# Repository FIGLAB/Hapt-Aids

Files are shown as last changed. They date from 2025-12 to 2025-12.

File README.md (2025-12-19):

# Hapt-Aids: Self-Powered, On-Body Haptics for Activity Monitoring
This is the repository for Hapt-Aids, presented at UBICOMP 2025. Check out the [full paper here](https://drive.google.com/file/d/1-sPkwGhYdYCn-X2jhVIx13SwtfONY48X/view?usp=sharing)!
Feel free to contact me with any questions!

The JLCPCB folder can be directly uploaded, and should also contain instructions for assembly of the PCB with all components other than the supercapacitor and the vibration motor.

If you want to edit the files, open the project in KICAD.
The full parts list can be found in the Bill of Materials.

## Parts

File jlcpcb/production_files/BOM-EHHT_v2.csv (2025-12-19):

Comment | Designator | Footprint | LCSC
MCR16 | D3 | MCR16
A+ | H4 | PinHeader_1x01_P1.00mm_Vertical
0.01uF | CREF1 | Capacitor_SMD:C_0402_1005Metric
O+ | H13 | PinHeader_1x01_P1.00mm_Vertical
4.42M | RUV2 | Resistor_SMD:R_0402_1005Metric
0.1uF | CBYP1 | Capacitor_SMD:C_0402_1005Metric
4.7uF | CHVR1 | Capacitor_SMD:C_0402_1005Metric
10M | ROC1 | Resistor_SMD:R_0402_1005Metric
5.62M | ROC12 | Resistor_SMD:R_0402_1005Metric
4.22M | ROK2 | Resistor_SMD:R_0402_1005Metric
DC+ | H1 | PinHeader_1x01_P1.00mm_Vertical
BQ25504RGTT | U1 | RGT16_1P7X1P7
4.7uF | CSTOR1 | Capacitor_SMD:C_0402_1005Metric
SKTAACE010 | S1 | SKTAACE010
3313J-1-100E | R1 | TRIM_3313J-1-100E
DC- | H2 | PinHeader_1x01_P1.00mm_Vertical
4.42M | ROK1 | Resistor_SMD:R_0402_1005Metric
100 | ROK4 | Resistor_SMD:R_0402_1005Metric
MM3Z5V1W | D1 | D_SOD-323
47uF | C_AC1 | Capacitor_SMD:C_0603_1608Metric
4.02M | ROV2 | Resistor_SMD:R_0402_1005Metric
KMB24F | KMB24F1 | DIO-BG-SMD_MBF-TL
C+ | H7 | PinHeader_1x01_P1.00mm_Vertical
4.42M | ROC2 | Resistor_SMD:R_0402_1005Metric
AC+ | H5 | PinHeader_1x01_P1.00mm_Vertical
C- | H6 | PinHeader_1x01_P1.00mm_Vertical
3313J-1-204E | R2 | TRIM_3313J-1-100E
22uH | L1 | CMLW4030S220MST
5.6M | RUV1 | Resistor_SMD:R_0402_1005Metric
GND | H9 | PinHeader_1x01_P1.00mm_Vertical
MM3Z5V1W | D2 | D_SOD-323
5.9M | ROV1 | Resistor_SMD:R_0402_1005Metric
O- | H14 | PinHeader_1x01_P1.00mm_Vertical
1.43M | ROK3 | Resistor_SMD:R_0402_1005Metric
A- | H3 | PinHeader_1x01_P1.00mm_Vertical

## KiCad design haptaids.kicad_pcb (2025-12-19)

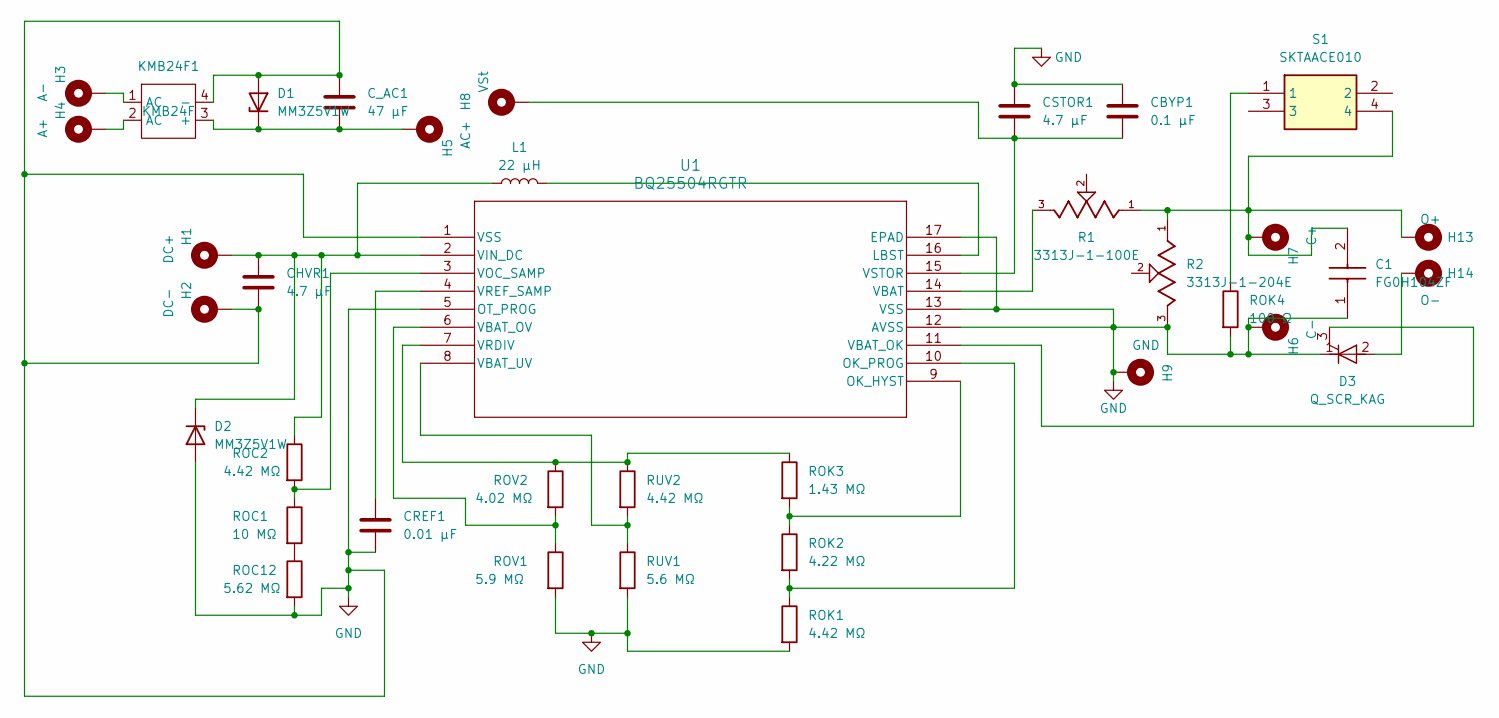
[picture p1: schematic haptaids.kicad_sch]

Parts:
C1: FG0H104ZF; CAPPRD508W114D1100H650; Mouser Part Number 80-FG0H104ZF
CBYP1: 0.1 μF; C_0402_1005Metric
CHVR1: 4.7 μF; C_0402_1005Metric
CREF1: 0.01 μF; C_0402_1005Metric
CSTOR1: 4.7 μF; C_0402_1005Metric
C_AC1: 47 μF; C_0603_1608Metric
D1, D2: MM3Z5V1W; D_SOD-323
D3: Q_SCR_KAG; SCR_small
H1: DC+; PinHeader_1x01_P1.00mm_Vertical
H2: DC-; PinHeader_1x01_P1.00mm_Vertical
H3: A-; PinHeader_1x01_P1.00mm_Vertical
H4: A+; PinHeader_1x01_P1.00mm_Vertical
H5: AC+; PinHeader_1x01_P1.00mm_Vertical
H6: C-; PinHeader_1x01_P1.00mm_Vertical
H7: C+; PinHeader_1x01_P1.00mm_Vertical
H9: GND; PinHeader_1x01_P1.00mm_Vertical
H13: O+; PinHeader_1x01_P1.00mm_Vertical
H14: O-; PinHeader_1x01_P1.00mm_Vertical
KMB24F1: KMB24F; DIO-BG-SMD_MBF-TL
L1: 22 μH; L_Changjiang_FNR4026S
R1: 3313J-1-100E; TRIM_3313J-1-100E; PARTREV 08/19
R2: 3313J-1-204E; TRIM_3313J-1-100E; PARTREV 08/19
ROC1: 10 MΩ; R_0402_1005Metric
ROC2: 4.42 MΩ; R_0402_1005Metric
ROC12: 5.62 MΩ; R_0402_1005Metric
ROK1: 4.42 MΩ; R_0402_1005Metric
ROK2: 4.22 MΩ; R_0402_1005Metric
ROK3: 1.43 MΩ; R_0402_1005Metric
ROK4: 100 Ω; R_0402_1005Metric
ROV1: 5.9 MΩ; R_0402_1005Metric
ROV2: 4.02 MΩ; R_0402_1005Metric
RUV1: 5.6 MΩ; R_0402_1005Metric
RUV2: 4.42 MΩ; R_0402_1005Metric
S1: SKTAACE010; Mouser Part Number 688-SKTAACE010
U1: BQ25504RGTR; RGT16_1P7X1P7
VSt: H8; PinHeader_1x01_P1.00mm_Vertical

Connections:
GND: C1.1 (+), CBYP1.2, CHVR1.1, CREF1.1, CSTOR1.2, C_AC1.2, D1.2 (A), D2.2 (A), D3.1 (K), H2.1, H6.1, H9.1, KMB24F1.4 (-), R2.3, ROC12.2, ROK1.2, ROK4.2, ROV1.2, RUV1.2, U1.1 (VSS), U1.5 (OT_PROG), U1.12 (AVSS), U1.13 (VSS), U1.17 (EPAD)
unnamed: C1.2 (-), H7.1, H13.1, R1.1, R2.1, S1.4
unnamed: C_AC1.1, D1.1 (K), H5.1, KMB24F1.3 (+)
unnamed: CHVR1.2, D2.1 (K), H1.1, L1.1, ROC2.1, U1.2 (VIN_DC)
unnamed: D3.2 (A), H14.1
unnamed: D3.3 (G), U1.11 (VBAT_OK)
unnamed: H3.1, KMB24F1.1 (AC)
unnamed: H4.1, KMB24F1.2 (AC)
unnamed: ROC1.2, ROC12.1
unnamed: ROK4.1, S1.1
unnamed: L1.2, U1.16 (LBST)
unnamed: ROK2.1, ROK3.2, U1.9 (OK_HYST)
unnamed: ROK1.1, ROK2.2, U1.10 (OK_PROG)
unnamed: R1.3, U1.14 (VBAT)
unnamed: ROV1.1, ROV2.2, U1.6 (VBAT_OV)
unnamed: RUV1.1, RUV2.2, U1.8 (VBAT_UV)
unnamed: ROC1.1, ROC2.2, U1.3 (VOC_SAMP)
unnamed: ROK3.1, ROV2.1, RUV2.1, U1.7 (VRDIV)
unnamed: CREF1.2, U1.4 (VREF_SAMP)
unnamed: CBYP1.1, CSTOR1.1, U1.15 (VSTOR), VSt.1

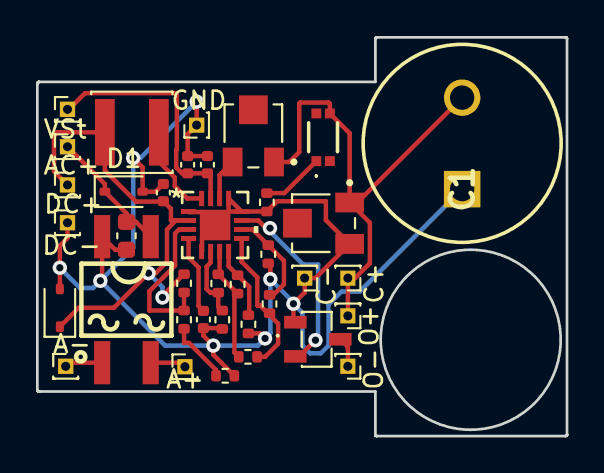
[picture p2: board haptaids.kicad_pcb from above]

Board: 2 copper layers, 29.4 x 22.2 mm, 37 parts (0 on the bottom side), 20 nets.
